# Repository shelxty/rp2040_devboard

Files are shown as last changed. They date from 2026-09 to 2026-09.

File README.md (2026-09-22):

# RP2040 Devboard

This is a compact, breakout-friendly devboard (2-layer PCB) built around the Raspberry Pi 2040 microcontroller. It contains an onboard QSPI flash, USB-C, and 30 GPIO pins broken out to dual 20-pin headers. 

It's designed as a base for embedded projects, with every usable GPIO routed to a header pin to be used on a breadboard or custom carrier PCB. 

## Components 

| Reference | Part | Description | Package | 
| --- | ----- | --- | --- |
| U1 | RP2040 | Dual-core MCU | QFN-56, 7x7 mm | 
| U2 | MCPI1700-3.3 | 3.3V LDO regulator | SOT-89-3 | 
| U3 | W25Q128JVS | 16 MB QSPI flash | USON-3, 3x2 mm | 
| Y1 | Crystal | 12 MHz (GND24 style) | 3.2x2.5 mm SMD | 
| J1 | USB-C receptacle | USB 2.0, 14-pin | SMD | 
| J2 | Pin header | GPIO breakout, 1x20 | 2.54 mm THT | 
| SW1 | Tactile switch | BOOTSEL button | SMD | 
| R1, R2 | 5.1kΩ | USB-C CC1/CC2 pull-downs | 0402 |
| R3, R4 | 27Ω | USB D+/D- series termination | 0402 | 
| R5, R7 | 1kΩ | Damping resistors | 0402 |
| R6 | 10kΩ | Standard resistor value from datasheet | 0402 | 
| C1 - C8, C10, C11, C17 | 0.1µF | Decoupling capacitors | 0402 | 
| C9, C12 | 1µF | Decoupling/bulk capacitors | 0402 | 
| C13, C14 | 10µF | Bulk/regulator capacitors | 0603 | 
| C15, C16 | 33pF | Crystal load capacitors | 0201 |

## Flashing and Debugging 

Connect a SWD debug probe to the header J4. 
| J4 Pin | Signal | 
| --- | --- |
| 1 | SWCLK | 
| 2 | SWD (SWDIO) | 
| 3 | GND | 

### Powering the Board

Power is supplied over a USB-C (VBUS, 5V) regulated down to 3.3V by U2. No external supply is required for typical use. 

## Design Files



_Kinda messy schematic view_



_Really messy view of PCB design_



_uhhh view of the PCB 3D viewer_

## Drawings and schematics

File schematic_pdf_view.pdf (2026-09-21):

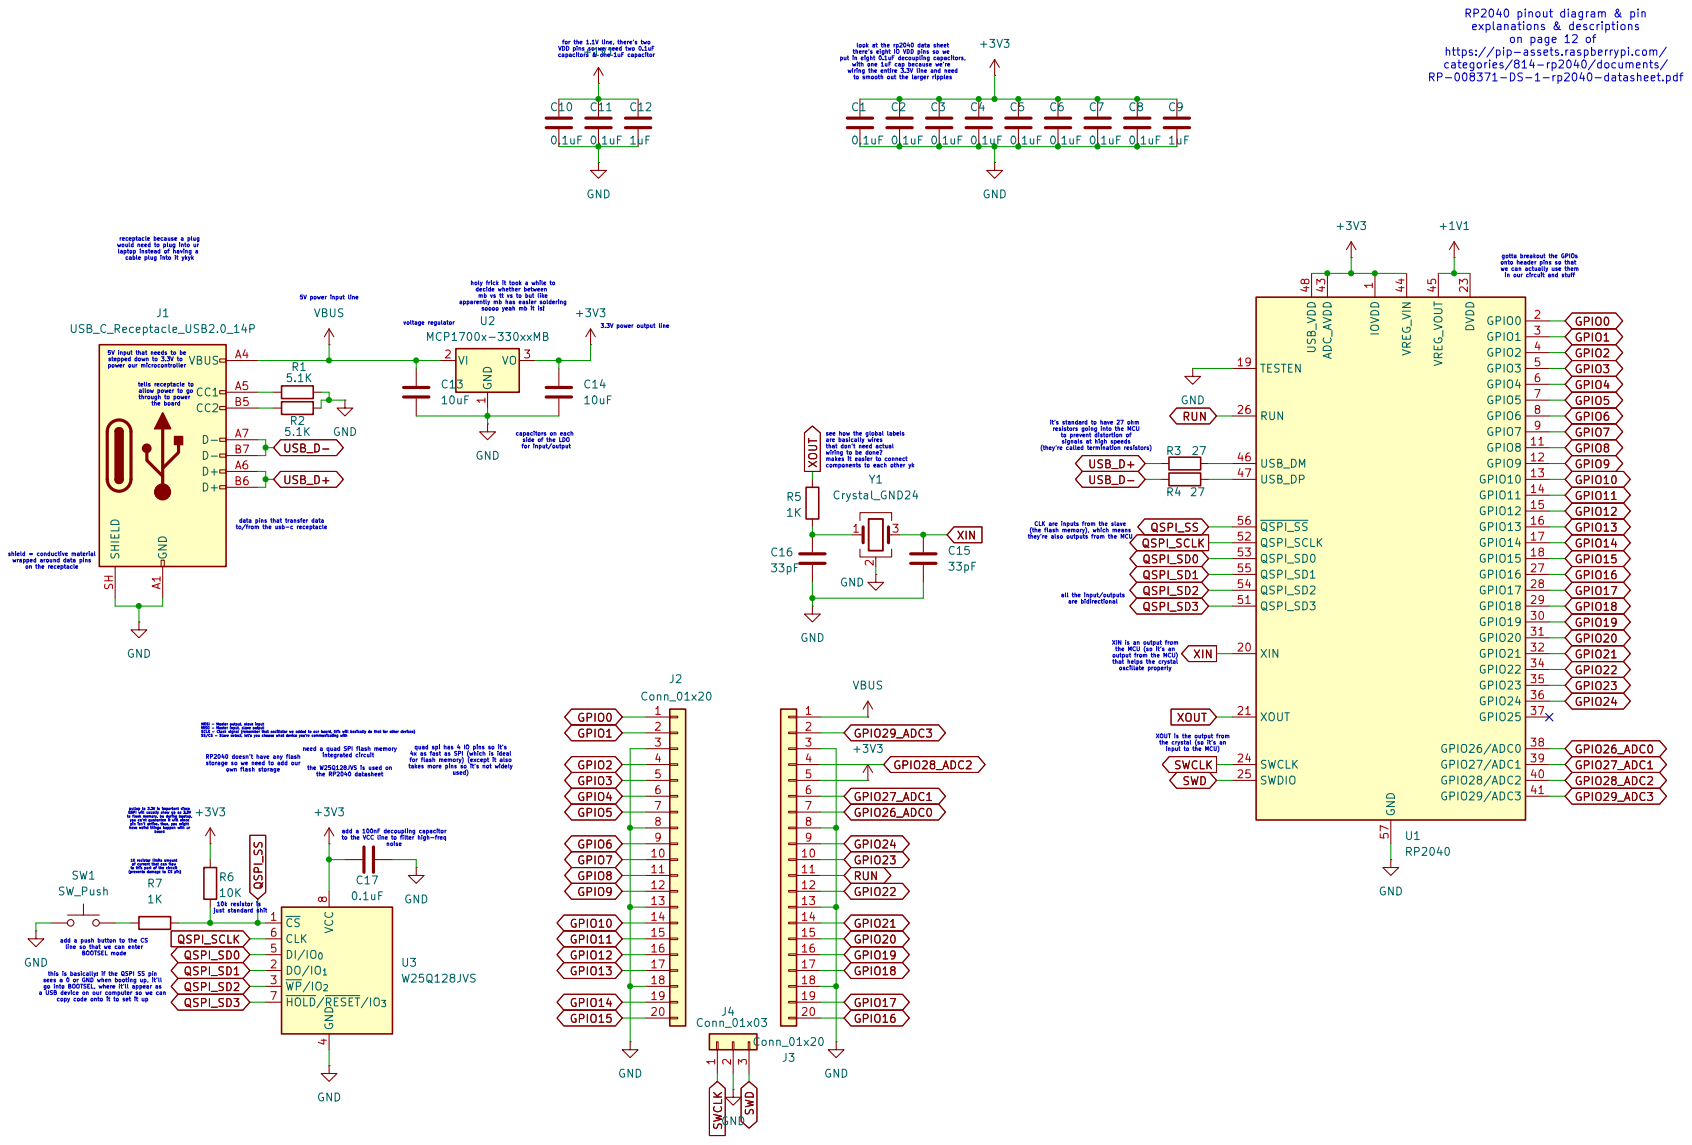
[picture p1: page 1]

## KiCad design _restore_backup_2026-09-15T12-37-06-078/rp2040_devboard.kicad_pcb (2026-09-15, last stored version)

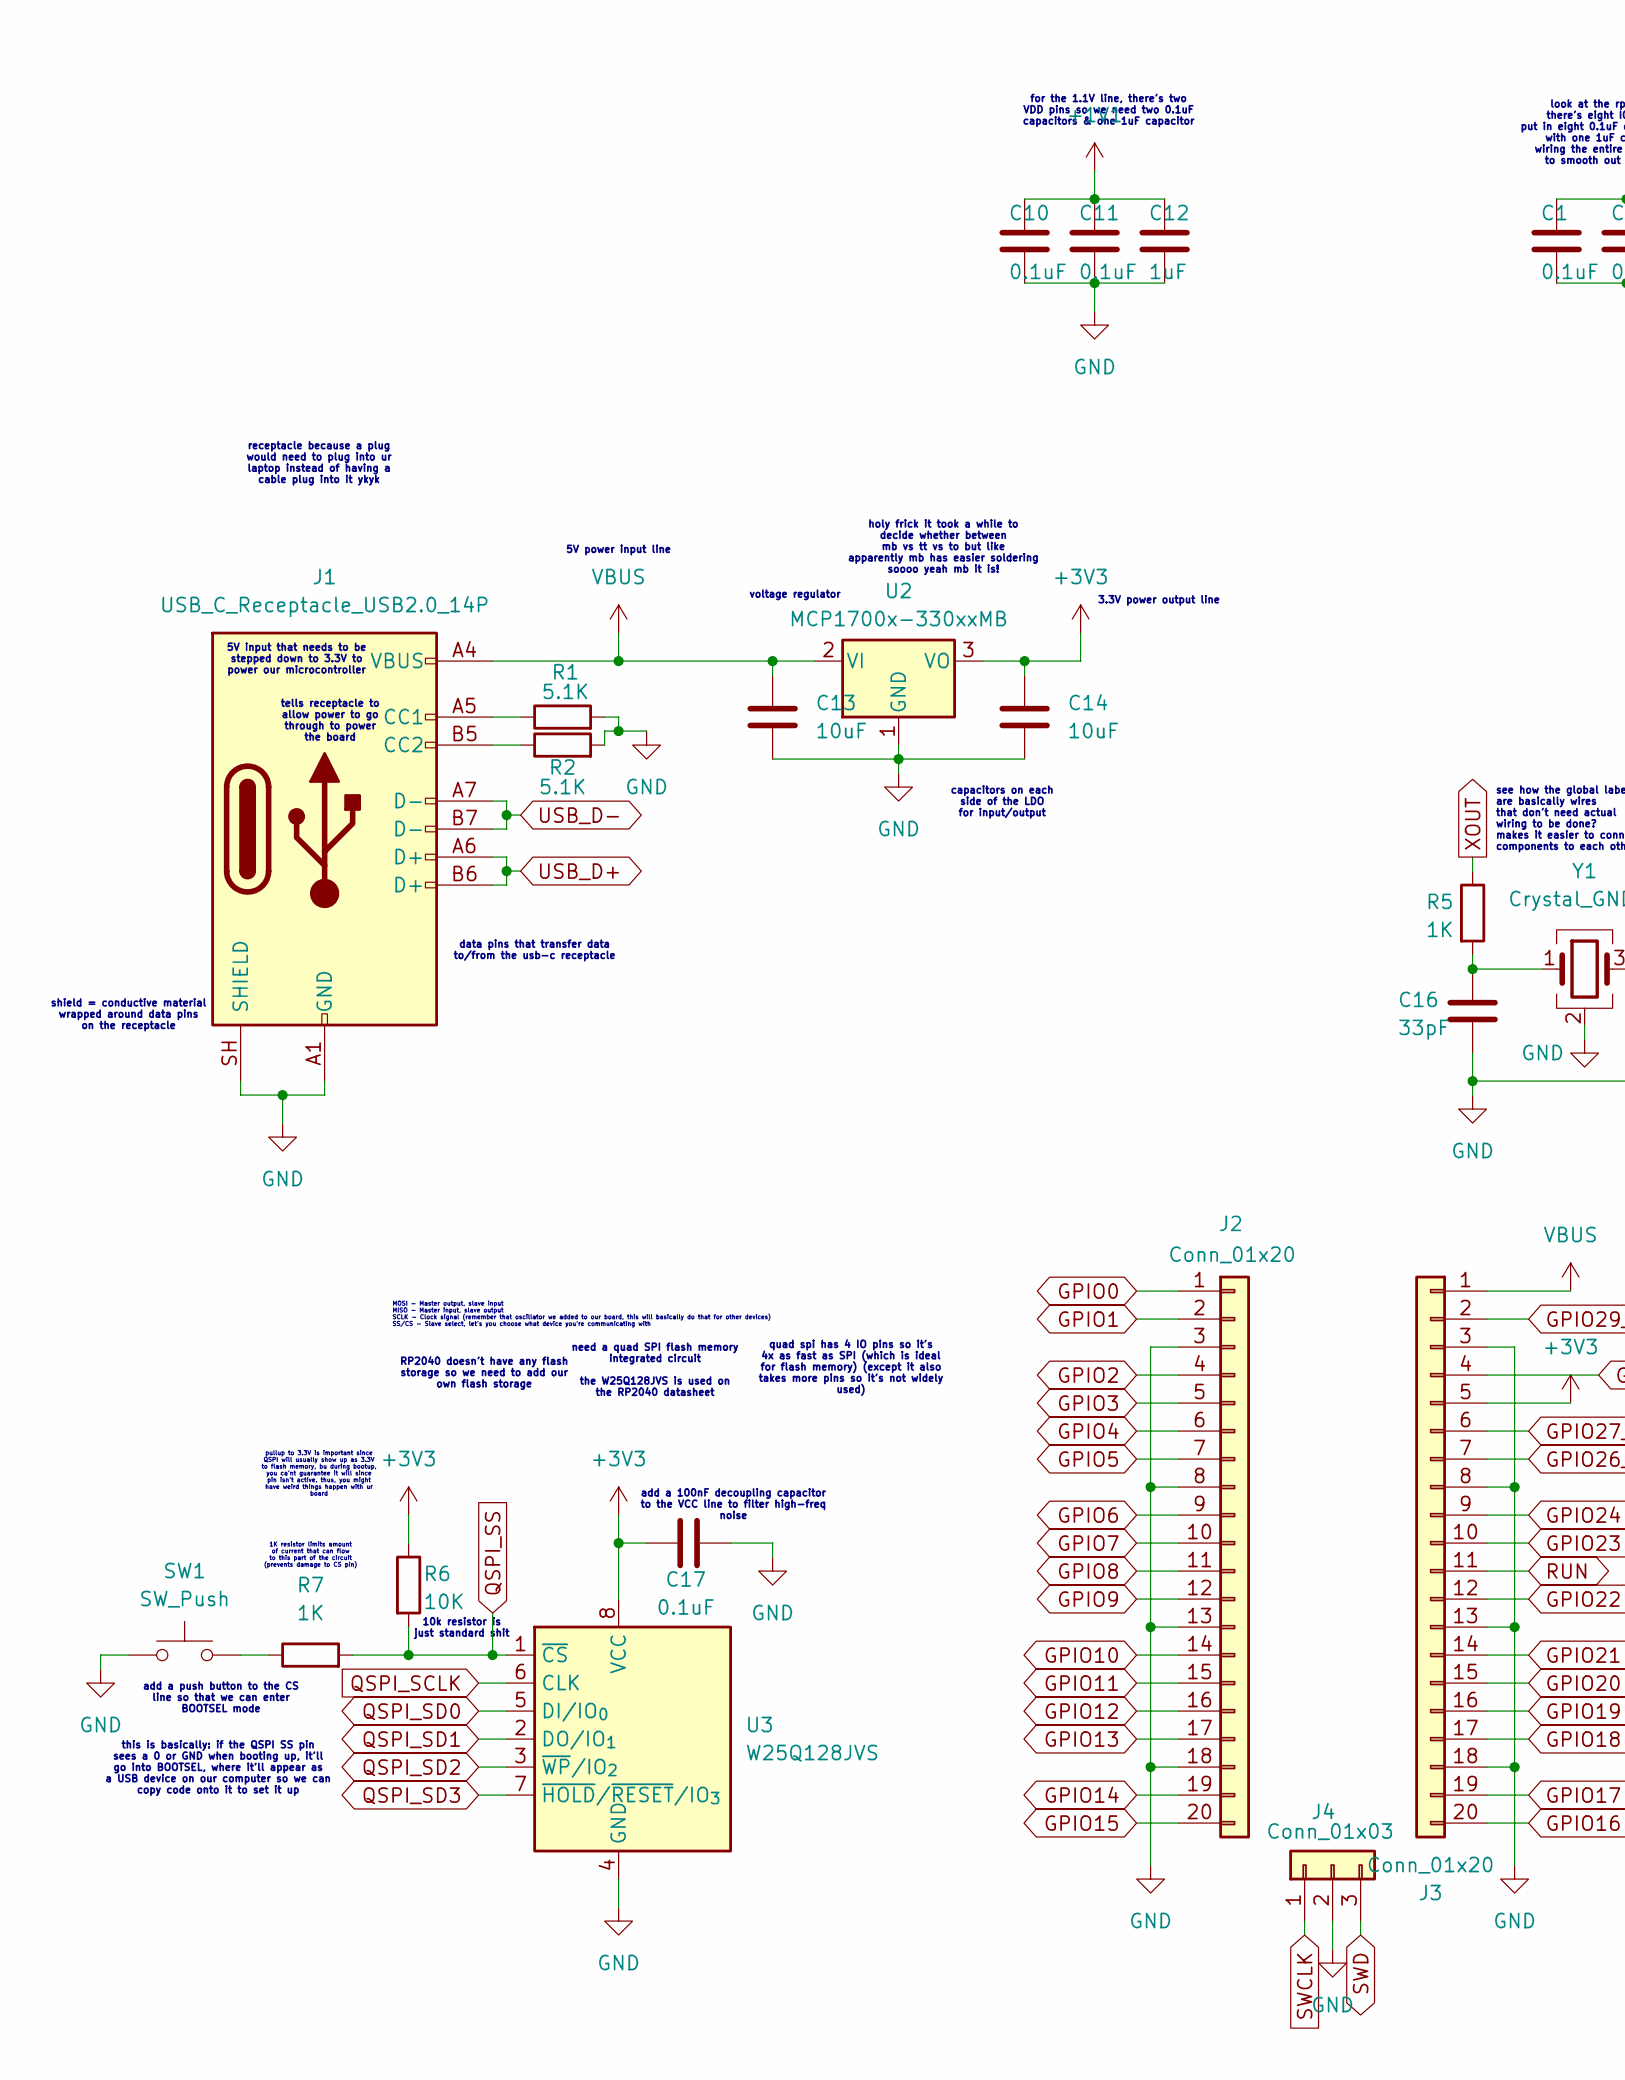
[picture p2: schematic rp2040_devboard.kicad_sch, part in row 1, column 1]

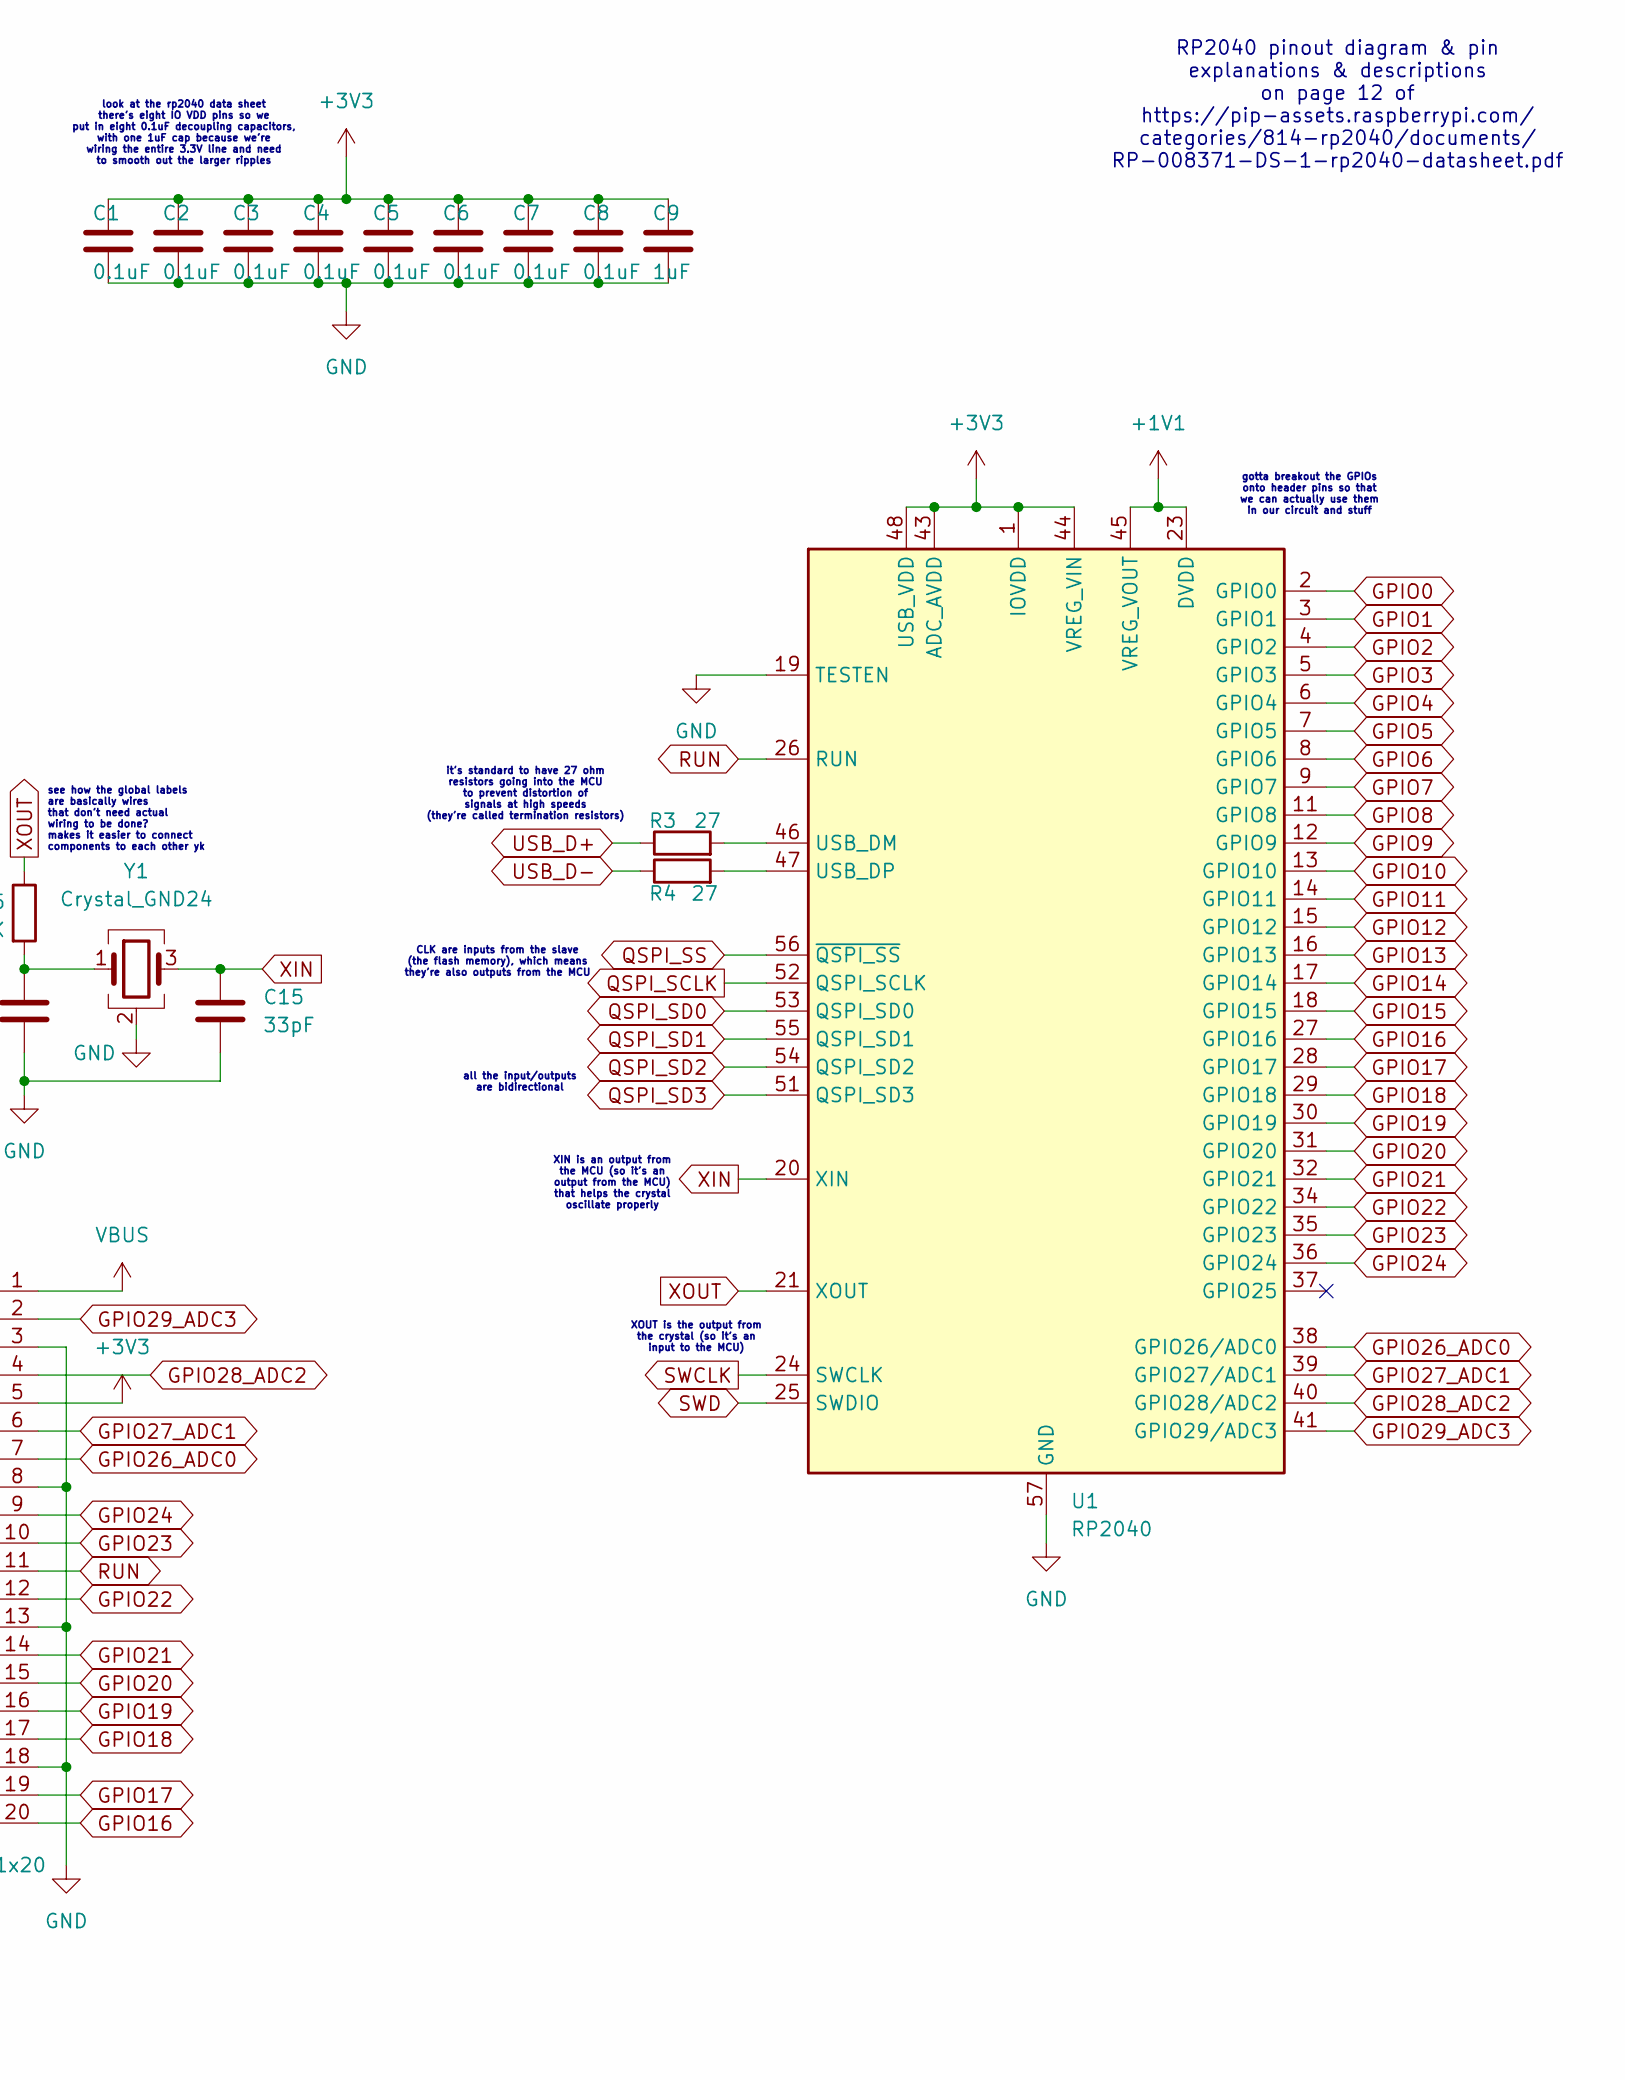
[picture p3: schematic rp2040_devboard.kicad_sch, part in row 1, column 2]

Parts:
C1, C2, C3, C4, C5, C6, C7, C8, C10, C11, C17: 0.1uF; C_0402_1005Metric
C9, C12: 1uF; C_0402_1005Metric
C13, C14: 10uF; C_0603_1608Metric
C15, C16: 33pF; C_0201_0603Metric
J1: USB_C_Receptacle_USB2.0_14P; USB_C_Receptacle_HRO_TYPE-C-31-M-12
J2, J3: Conn_01x20; PinHeader_1x20_P2.54mm_Vertical
J4: Conn_01x03; PinHeader_1x03_P2.54mm_Vertical
R1, R2: 5.1K; R_0402_1005Metric
R3, R4: 27; R_0402_1005Metric
R5, R7: 1K; R_0402_1005Metric
R6: 10K; R_0402_1005Metric
SW1: SW_Push; SW_Push_SPST_NO_Alps_SKRK
U1: RP2040; QFN-56-1EP_7x7mm_P0.4mm_EP3.2x3.2mm
U2: MCP1700x-330xxMB; SOT-89-3
U3: W25Q128JVS; Winbond_USON-8-1EP_3x2mm_P0.5mm_EP0.2x1.6mm
Y1: Crystal_GND24; Crystal_SMD_3225-4Pin_3.2x2.5mm

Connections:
+1V1: C10.1, C11.1, C12.1, U1.23 (DVDD), U1.45 (VREG_VOUT), U1.50 (DVDD)
+3V3: C1.1, C2.1, C3.1, C4.1, C5.1, C6.1, C7.1, C8.1, C9.1, C14.1, C17.1, J3.5, R6.1, U1.1 (IOVDD), U1.10 (IOVDD), U1.22 (IOVDD), U1.33 (IOVDD), U1.42 (IOVDD), U1.43 (ADC_AVDD), U1.44 (VREG_VIN), U1.48 (USB_VDD), U1.49 (IOVDD), U2.3 (VO), U3.8 (VCC)
GND: C1.2, C2.2, C3.2, C4.2, C5.2, C6.2, C7.2, C8.2, C9.2, C10.2, C11.2, C12.2, C13.2, C14.2, C15.1, C16.2, C17.2, J1.A1 (GND), J1.A12 (GND), J1.B1 (GND), J1.B12 (GND), J1.SH (SHIELD), J2.3, J2.8, J2.13, J2.18, J3.3, J3.8, J3.13, J3.18, J4.2, R1.2, R2.2, SW1.1, U1.19 (TESTEN), U1.57 (GND), U2.1 (GND), U3.4 (GND), Y1.2 (G), Y1.4 (G)
GPIO0: J2.1, U1.2 (GPIO0)
GPIO1: J2.2, U1.3 (GPIO1)
GPIO2: J2.4, U1.4 (GPIO2)
GPIO3: J2.5, U1.5 (GPIO3)
GPIO4: J2.6, U1.6 (GPIO4)
GPIO5: J2.7, U1.7 (GPIO5)
GPIO6: J2.9, U1.8 (GPIO6)
GPIO7: J2.10, U1.9 (GPIO7)
GPIO8: J2.11, U1.11 (GPIO8)
GPIO9: J2.12, U1.12 (GPIO9)
GPIO10: J2.14, U1.13 (GPIO10)
GPIO11: J2.15, U1.14 (GPIO11)
GPIO12: J2.16, U1.15 (GPIO12)
GPIO13: J2.17, U1.16 (GPIO13)
GPIO14: J2.19, U1.17 (GPIO14)
GPIO15: J2.20, U1.18 (GPIO15)
GPIO16: J3.20, U1.27 (GPIO16)
GPIO17: J3.19, U1.28 (GPIO17)
GPIO18: J3.17, U1.29 (GPIO18)
GPIO19: J3.16, U1.30 (GPIO19)
GPIO20: J3.15, U1.31 (GPIO20)
GPIO21: J3.14, U1.32 (GPIO21)
GPIO22: J3.12, U1.34 (GPIO22)
GPIO23: J3.10, U1.35 (GPIO23)
GPIO24: J3.9, U1.36 (GPIO24)
GPIO26_ADC0: J3.7, U1.38 (GPIO26/ADC0)
GPIO27_ADC1: J3.6, U1.39 (GPIO27/ADC1)
GPIO28_ADC2: J3.4, U1.40 (GPIO28/ADC2)
GPIO29_ADC3: J3.2, U1.41 (GPIO29/ADC3)
unnamed: C16.1, R5.2, Y1.1
unnamed: J1.A5 (CC1), R1.1
unnamed: J1.B5 (CC2), R2.1
unnamed: R7.1, SW1.2
unnamed: R3.2, U1.46 (USB_DM)
unnamed: R4.2, U1.47 (USB_DP)
QSPI_SCLK: U1.52 (QSPI_SCLK), U3.6 (CLK)
QSPI_SD0: U1.53 (QSPI_SD0), U3.5 (DI/IO_{0})
QSPI_SD1: U1.55 (QSPI_SD1), U3.2 (DO/IO_{1})
QSPI_SD2: U1.54 (QSPI_SD2), U3.3 (~WP/IO_{2})
QSPI_SD3: U1.51 (QSPI_SD3), U3.7 (~HOLD/~RESET/IO_{3})
QSPI_SS: R6.2, R7.2, U1.56 (~QSPI_SS), U3.1 (~CS)
RUN: J3.11, U1.26 (RUN)
SWCLK: J4.1, U1.24 (SWCLK)
SWD: J4.3, U1.25 (SWDIO)
USB_D+: J1.A6 (D+), J1.B6 (D+), R3.1
USB_D-: J1.A7 (D-), J1.B7 (D-), R4.1
VBUS: C13.1, J1.A4 (VBUS), J1.A9 (VBUS), J1.B4 (VBUS), J1.B9 (VBUS), J3.1, U2.2 (VI)
XIN: C15.2, U1.20 (XIN), Y1.3
XOUT: R5.1, U1.21 (XOUT)

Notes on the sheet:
XOUT is the output from the crystal (so it's an input to the MCU)
tells receptacle to allow power to go through to power the board
look at the rp2040 data sheet there's eight IO VDD pins so we put in eight 0.1uF decoupling capacitors, with one 1uF cap because we're wiring the entire 3.3V line and need to smooth out the larger ripples
all the input/outputs are bidirectional
XIN is an output from the MCU (so it's an output from the MCU) that helps the crystal oscillate properly
capacitors on each side of the LDO for input/output
10k resistor is just standard shit
pullup to 3.3V is important since QSPI will usually show up as 3.3V to flash memory, bu during bootup, you ca'nt guarantee it will since pin isn't active. thus, you might have weird things happen with ur board
5V power input line
MOSI - Master output, slave input MISO - Master input, slave output SCLK - Clock signal (remember that oscillator we added to our board, this will basically do that for other devices) SS/CS - Slave select, let's you choose what device you're communicating with
add a 100nF decoupling capacitor to the VCC line to filter high-freq noise
quad spi has 4 IO pins so it's 4x as fast as SPI (which is ideal for flash memory) (except it also takes more pins so it's not widely used)
RP2040 pinout diagram & pin explanations & descriptions on page 12 of https://pip-assets.raspberrypi.com/ categories/814-rp2040/documents/ RP-008371-DS-1-rp2040-datasheet.pdf
this is basically: if the QSPI SS pin sees a 0 or GND when booting up, it'll go into BOOTSEL, where it'll appear as a USB device on our computer so we can copy code onto it to set it up
receptacle because a plug would need to plug into ur laptop instead of having a cable plug into it ykyk
1K resistor limits amount of current that can flow to this part of the circuit (prevents damage to CS pin)
add a push button to the CS line so that we can enter BOOTSEL mode
CLK are inputs from the slave (the flash memory), which means they're also outputs from the MCU
3.3V power output line
shield = conductive material wrapped around data pins on the receptacle
gotta breakout the GPIOs onto header pins so that we can actually use them in our circuit and stuff
need a quad SPI flash memory integrated circuit the W25Q128JVS is used on the RP2040 datasheet
RP2040 doesn't have any flash storage so we need to add our own flash storage
data pins that transfer data to/from the usb-c receptacle
5V input that needs to be stepped down to 3.3V to power our microcontroller
voltage regulator
holy frick it took a while to decide whether between mb vs tt vs to but like apparently mb has easier soldering soooo yeah mb it is!
for the 1.1V line, there's two VDD pins so we need two 0.1uF capacitors & one 1uF capacitor
see how the global labels are basically wires that don't need actual wiring to be done? makes it easier to connect components to each other yk
it's standard to have 27 ohm resistors going into the MCU to prevent distortion of signals at high speeds (they're called termination resistors)

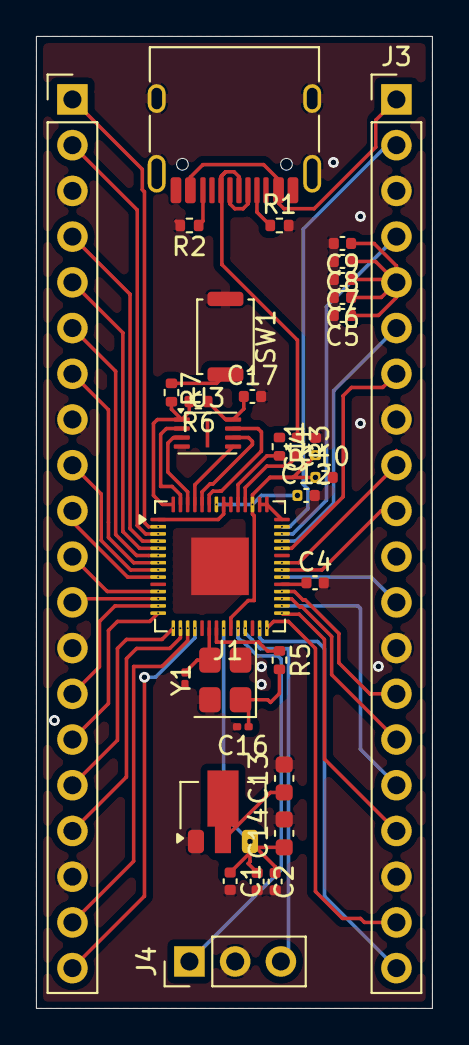
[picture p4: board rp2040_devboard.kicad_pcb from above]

Board: 2 copper layers, 22.0 x 54.0 mm, 33 parts (0 on the bottom side), 52 nets.

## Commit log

2026-09-04 added a few components to the schematic
    [rp2040_devboard.kicad_pcb, rp2040_devboard.kicad_sch]
2026-09-06 finished schematic; updated a few footprints; working on routing
    [rp2040_devboard.kicad_sch]
2026-09-08 i'm trash at routing what the hell is going on
    [rp2040_devboard.kicad_pcb]
2026-09-08 routing and copper fill
    [rp2040_devboard.kicad_pcb]
2026-09-11 added a lot of tracing and routing and stuff i dont undersand anything though
    [rp2040_devboard.kicad_pcb]
2026-09-13 fixed like 50 drc errors
    [rp2040_devboard.kicad_sch]
2026-09-13 so i was told my routing was trash. i'll redo it!
    [rp2040_devboard.kicad_pcb]
2026-09-14 i think i've routed this at least 5 times over at this point
    [rp2040_devboard.kicad_pcb]
2026-09-15 copper pours
    [rp2040_devboard.kicad_pcb]
2026-09-21 fixed like 10 drc errors
    [rp2040_devboard.kicad_pcb, rp2040_devboard.kicad_sch]
2026-09-21 Enhance README with detailed board information
    Added detailed description, components list, flashing instructions, and design files for the RP2040 Devboard.
2026-09-21 fixed resistor value explantions yes
2026-09-22 Add PCB 3D viewer image to README
    Added a new image to the README for the PCB 3D viewer.
